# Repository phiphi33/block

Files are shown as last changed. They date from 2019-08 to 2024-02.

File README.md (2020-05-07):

Cette page existe en [Français](https://gitlab.com/tedour/clip-and-block/-/blob/master/README.fr.md).

Clip & block is an open source construction kit (CC By‑SA 4.0). It can create solid structure for electronic projects with a 3D printer. Pieces can be assembly and removed easily for adding and remove components. It is still under development but i present my own projects at the end of this page.
You can follow me on [Mastodon](https://mastodon.social/web/accounts/918095).

# Quickstart in one hour
## Print your first Clip & block
Clip & block is easy to print (no support, it's possible to print it in any direction, not to much précision needed, shapes are simple). 

To start, clone the project locally [GitLab](https://gitlab.com/tedour/clip-and-block/).

First step, you will print first pieces :

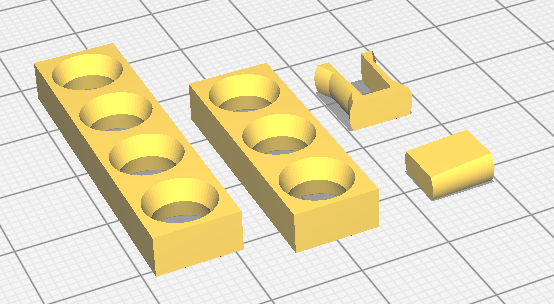
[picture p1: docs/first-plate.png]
first print


### For the pieces :
- go to directory [`stl/basic`](https://gitlab.com/tedour/clip-and-block/-/tree/master/stl/basic) ;
- get the file [`I-3.stl`](https://gitlab.com/tedour/clip-and-block/-/blob/master/stl/basic/I-3.stl) ;
- get the file [`I-4.stl`](https://gitlab.com/tedour/clip-and-block/-/blob/master/stl/basic/I-4.stl).
    
_`I-3.stl` → letter I is for the shape, number 3 is for number of holes._

### Pour le clip et le bloqueur :
- go to directory [`stl/clips`](https://gitlab.com/tedour/clip-and-block/-/tree/master/stl/clips) ;
- get the file [`blocker-2.stl`](https://gitlab.com/tedour/clip-and-block/-/blob/master/stl/clips/blocker-2.stl) (lay it flat, there is a function for that in Cura) ;
- get the file [`clip-2.stl`](https://gitlab.com/tedour/clip-and-block/-/blob/master/stl/clips/clip-2.stl).
    
_number 2 is for the height of the clip (for two pieces deux pièces). `blocker-2.stl` will work only with `clip-2.stl`._

You don't need two much materials for these pieces (2 g and 0,83 m with my settings). 
    
Now, you can assembly pieces ! To unmount, you need to push the blocker from the other side with a small tool. You can print other clips and blockers to play with it and see that it's strong !

# Pieces list
## Existing pieces 
In `stl/basic` directory, there is a big number of pieces (around 75). They are classified by shapes and number of holes (in three dimensions). Here is some samples :
    
| Nom | Image | Description |
| --- | --- | --- |
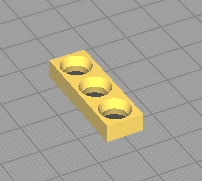
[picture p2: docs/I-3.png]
| I-3 |  | I : in length, 3 holes length |
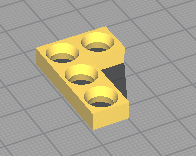
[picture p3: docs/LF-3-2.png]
LF
|  LF-3-2 |  | LF : in L flat, 3 holes length, 2 on the other side |
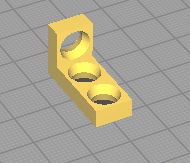
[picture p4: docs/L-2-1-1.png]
| L-2-1-1 |  | L : in L, 2 holes length, 1 height, 1 width |
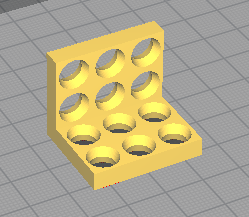
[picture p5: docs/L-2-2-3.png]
| L-2-2-3 |  | L : in L, 2 holes length, 2 height, 3 width |
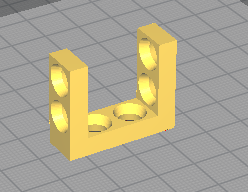
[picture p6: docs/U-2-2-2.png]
| U-2-2-2 |  | U : in  U |
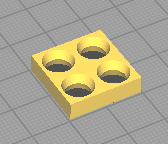
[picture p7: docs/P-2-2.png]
| P-2-2 |    | P : Flat |
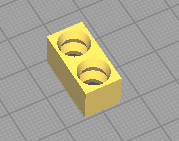
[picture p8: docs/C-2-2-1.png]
| C-2-2-1 |  | C : cube, 2 holes length, 2 height, 1 width |
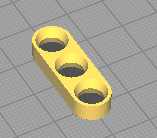
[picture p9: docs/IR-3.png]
| IR-3 |   | IR : in length, rounded (for pieces in rotation) |
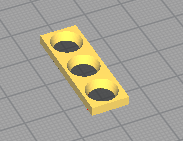
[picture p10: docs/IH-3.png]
| IH-3 |   | IH : in length, half height |
| IHR-3 |  I  | IHR : in length, half height, rounded |

_Perhaps i will remove some shape (C and P can do the same for example)…_

## Create your own pieces
If you can't find the piece you need, you can create your own with [OpenSCAD](https://www.openscad.org/), it's not so hard. For example, i describe here how to create piece P‑2‑3 (flat piece in 2 × 3) :
    
- open file [clip_and_block.scad](https://gitlab.com/tedour/clip-and-block/-/blob/master/clip_and_block.scad)
- modify `model` for the type to **P** ;
- modify `length1` for the length to **2** ;
- modify `length2` for the width to **3** ;
- you can preview with key `F6` ;
- and you can export to STL from OpenSCAD.
    
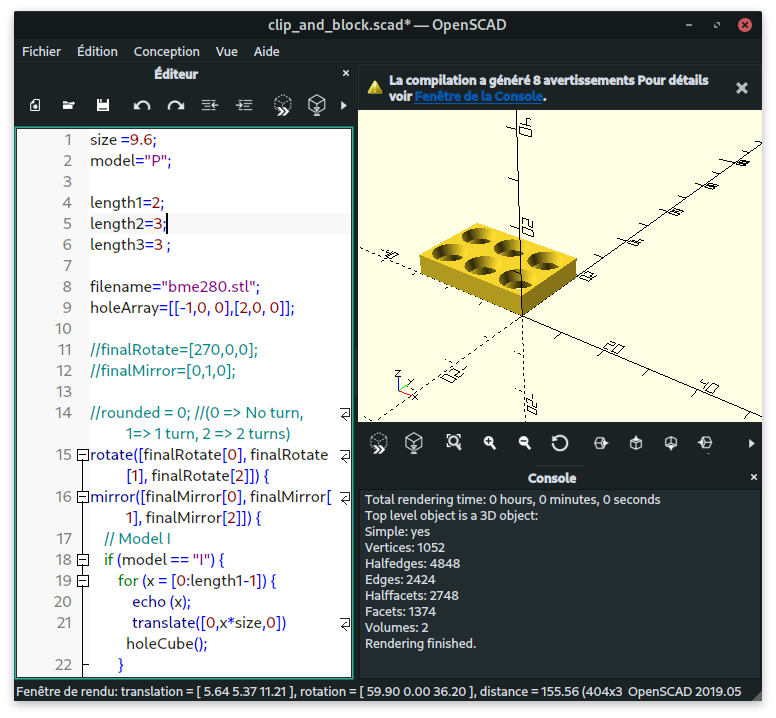
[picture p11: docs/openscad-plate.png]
OpenSCAD


# Pieces for electronic components
It's the interessant part of the project : you can integrate electronic components in clip&block.

## Existing components
I have create pieces for specific components. They are in the directory [`stl/electronic`](https://gitlab.com/tedour/clip-and-block/-/blob/master/stl/electronic).
    
For example, here are the two pieces that can include [NodeMCU](https://fr.wikipedia.org/wiki/NodeMCU) (I love this card :) ) :
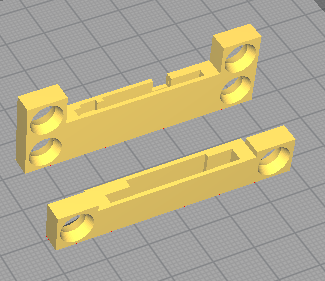
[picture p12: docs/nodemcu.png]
NodeMCU

    
There is a lot of types of this pieces, with more or less holes, only on one side, etc. Here is the list of components that you can find in Clip & block. This list is growing and is not up to date :
    
|  Nom | Image | Description |
| ---: | :----: | :---|
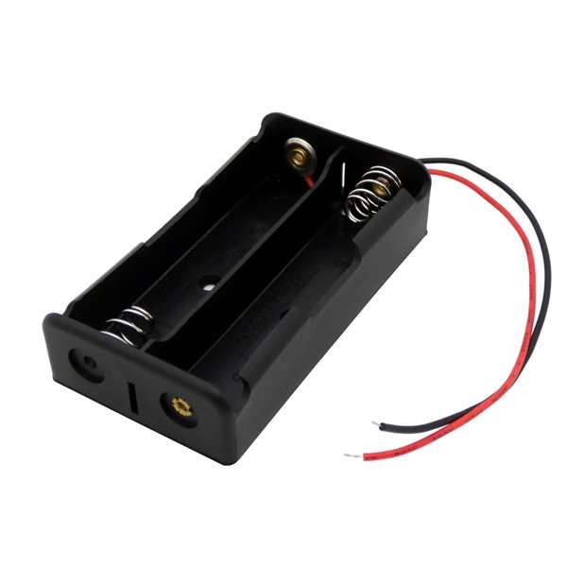
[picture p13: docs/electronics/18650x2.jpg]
|18650x2 Batterie holder |  | Power supply 7,4 V |
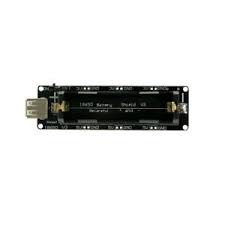
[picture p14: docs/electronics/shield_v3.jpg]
|18650 Batterie shield V3 |  |  Power supply USB + 3,3 V + 5 V + recharge |
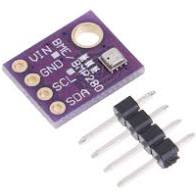
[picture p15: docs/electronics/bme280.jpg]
BME280
| BME 280 |  | Temperature |
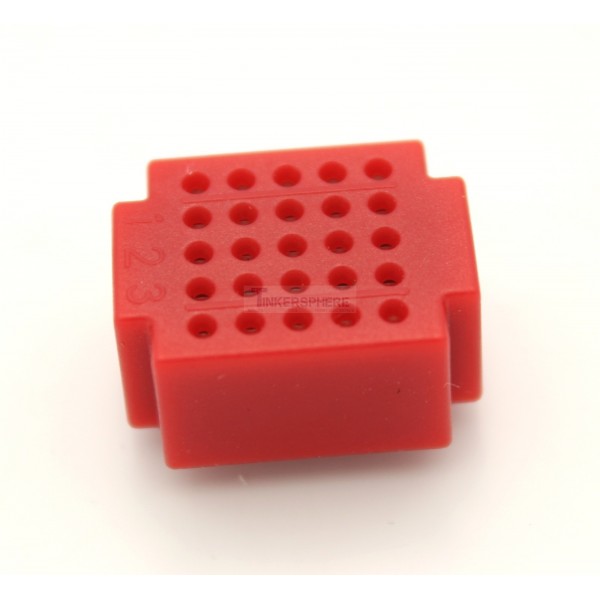
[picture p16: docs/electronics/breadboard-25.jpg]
breadboard25
| Breadboard 25 holes |  | Breadboard |
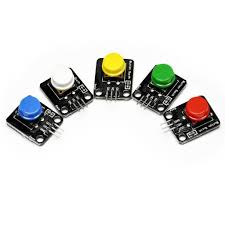
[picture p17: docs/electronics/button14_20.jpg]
button
| Button 14 × 20 |  | Button |
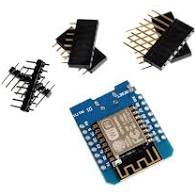
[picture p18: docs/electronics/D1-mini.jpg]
D1-mini
| D1 Mini |  | Developpement card |
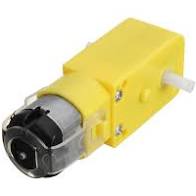
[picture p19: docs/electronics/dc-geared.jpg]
DC-motor
| DC Motor with gearbox |  | DC Motor |
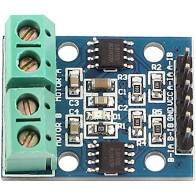
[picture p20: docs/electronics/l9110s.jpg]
l9110S
| L9110s Driver motor |  | DC motor driver
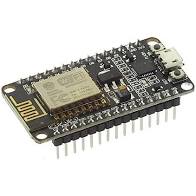
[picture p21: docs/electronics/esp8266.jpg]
nodemcu
| NodeMCU |  | Developpement card |
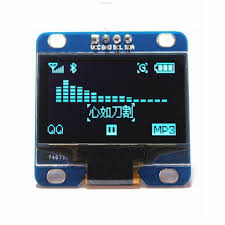
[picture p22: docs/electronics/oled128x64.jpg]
Afficheur OLED
| OLED 128 × 64 |  | OLED screen |
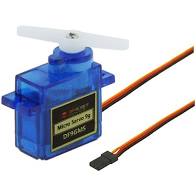
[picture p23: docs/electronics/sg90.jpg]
oled
| SG90 (une seule variante, à améliorer) |  | Servo motor |
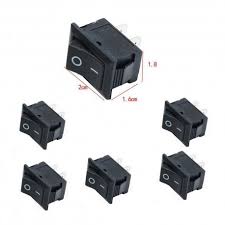
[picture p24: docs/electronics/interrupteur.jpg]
| Simple switch |  | Switch
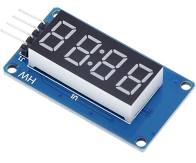
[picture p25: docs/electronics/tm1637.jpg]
| Display TM1637 |  | Display 4 × 7 segments |
    
I let you explore screenshots in the directory [`stl/electronic`].

## Create pieces for your own components
To create pieces for your own components you need to use your favorite CAD software to create the piece without holes. Your piece must be a multiple of 9,6mm length and with and a multiple of 4.8mm for the height.
    
After, you can had holes around your piece with OpenSCAD.

### Create the STL file of your component
Here is how i've worked with the TM1637 4-digit 7-segment :
    
- i've create a piece for the top and one for the bottom to "trap" the TM1637;
- next, i've create edges around to get a multiple of 9,6 mm (here, 48 mm : 5 holes × 28,8 mm et 3 holes × 4,8 mm heigth).
    
Top :
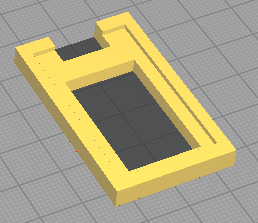
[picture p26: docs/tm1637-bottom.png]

    
Bottom :
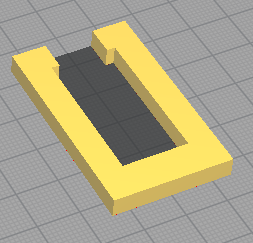
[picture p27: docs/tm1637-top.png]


### Adding holes with OpenScad
    
- open file [`clip_and_block.scad`](https://gitlab.com/tedour/clip-and-block/-/blob/master/clip_and_block.scad) ;
- put your STL file in the directory [`import`](https://gitlab.com/tedour/clip-and-block/-/blob/master/import) ;
- modify the parameter `model` for the type of piece at **F** (_Filename_) — for half height, choose **FH** ;
- in the array **holeArray**, enter coordinates of the holes (test to find the good ones) ;
- in the array **finalRotate**, you can turn your final piece;
- in the array **finalMirror**, you can mirror your final piece.
    
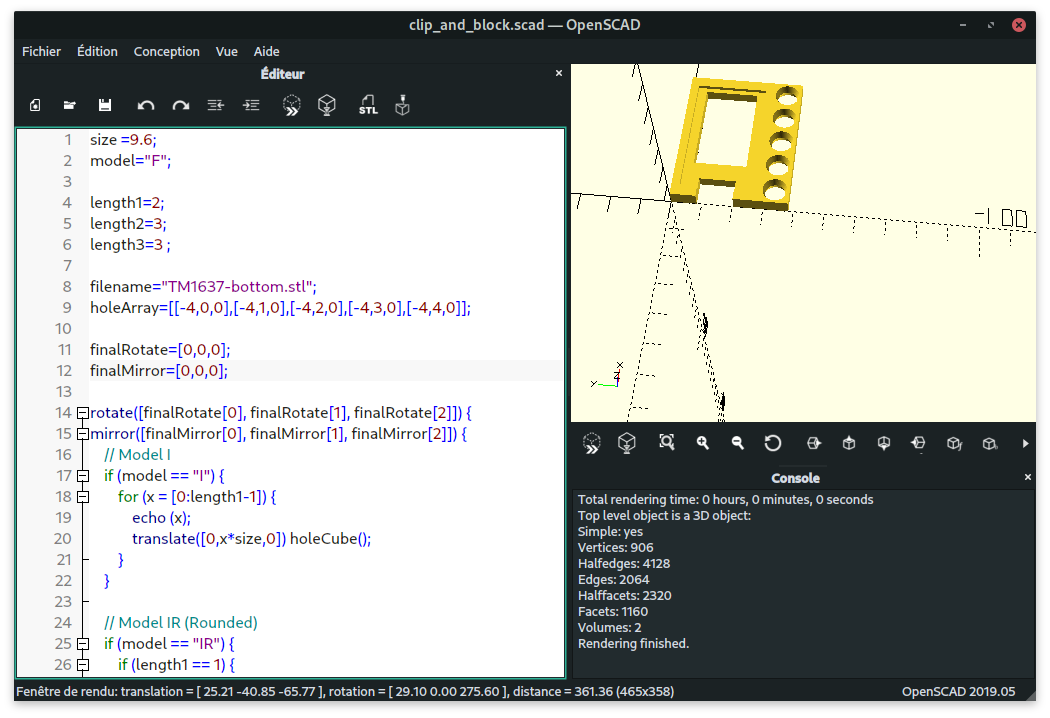
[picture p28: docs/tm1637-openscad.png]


# My projects with Clip&Block
Here are the projects i've create with Clip & blocks — feel free to ask me if you want more details about them :
    
- [Virtual Wall Roomba](https://www.thingiverse.com/thing:3413412) (mur virtuel pour aspirateur automatique) :
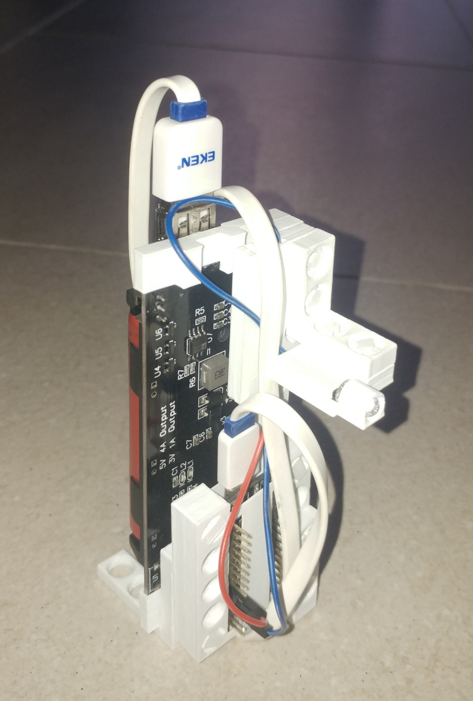
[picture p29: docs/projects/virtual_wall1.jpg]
Virtual Wall

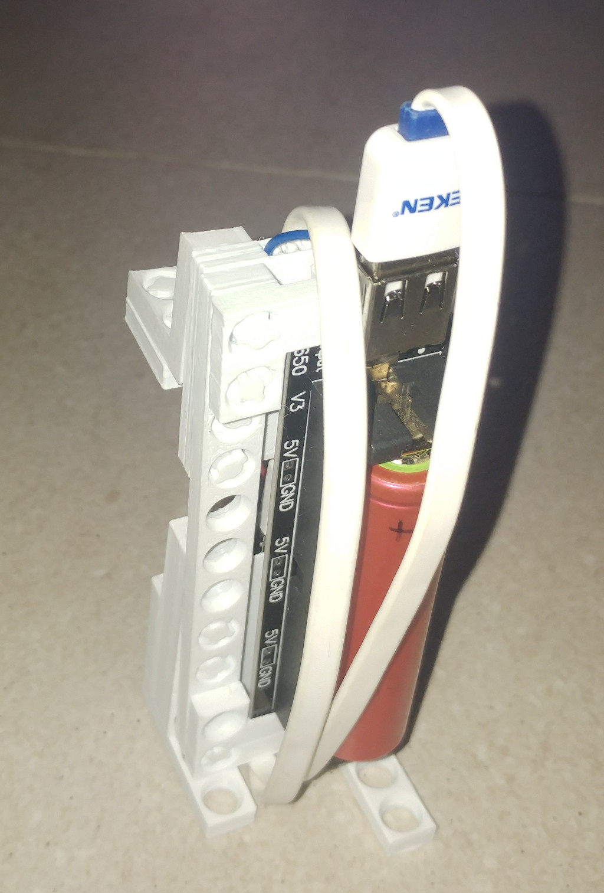
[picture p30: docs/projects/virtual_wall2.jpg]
Virtual Wall

    
- [electronic hourglass](https://www.thingiverse.com/thing:3413412) (To use in the morning with my childrens :)) :
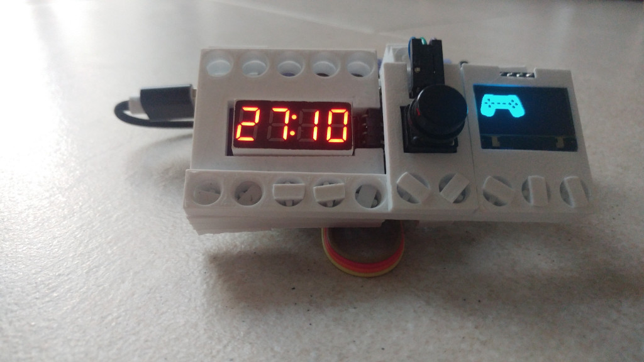
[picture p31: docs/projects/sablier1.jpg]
Sablier

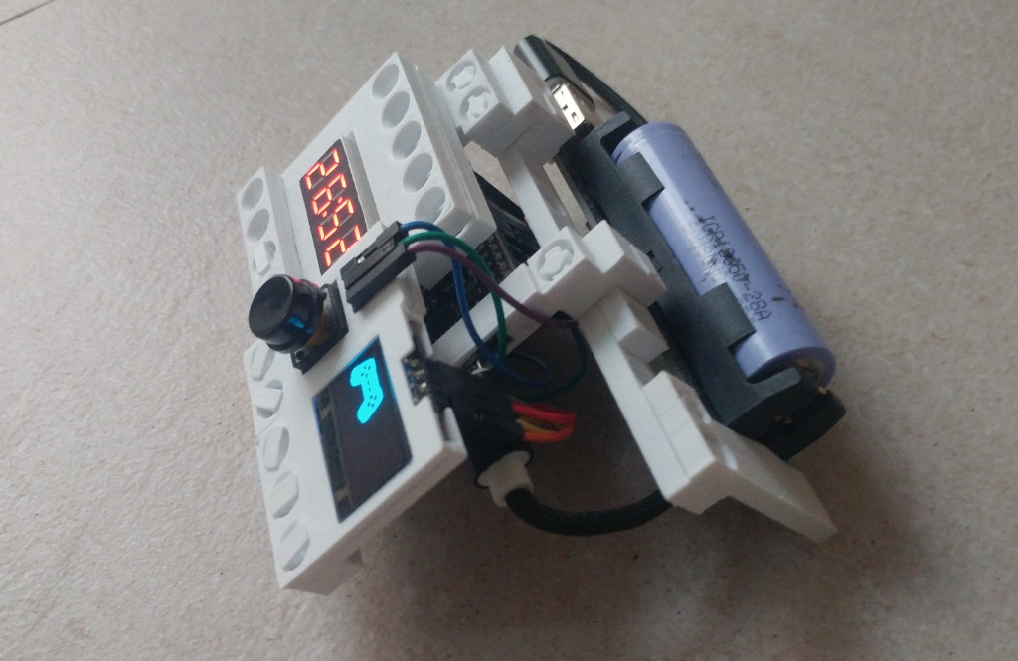
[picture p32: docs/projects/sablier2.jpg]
Sablier

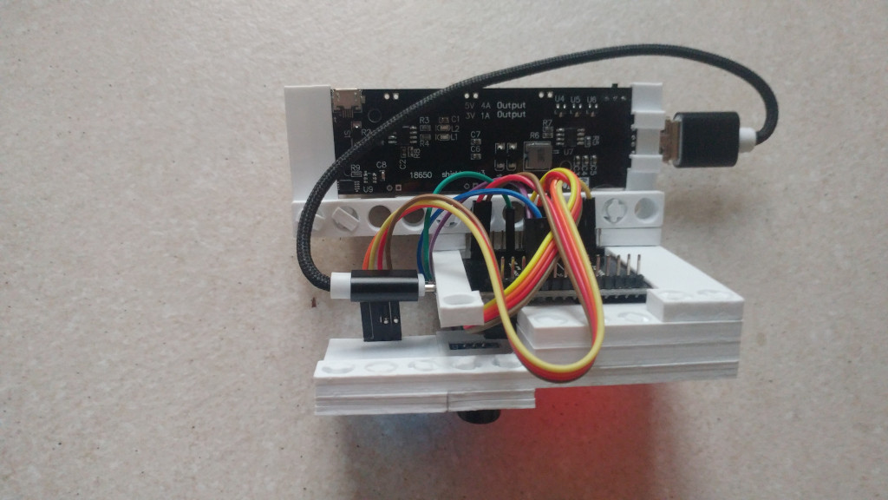
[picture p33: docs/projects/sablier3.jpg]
Sablier

    
- RC-CAR (based on my project [FF RC-Car](https://www.thingiverse.com/thing:3133996)) :
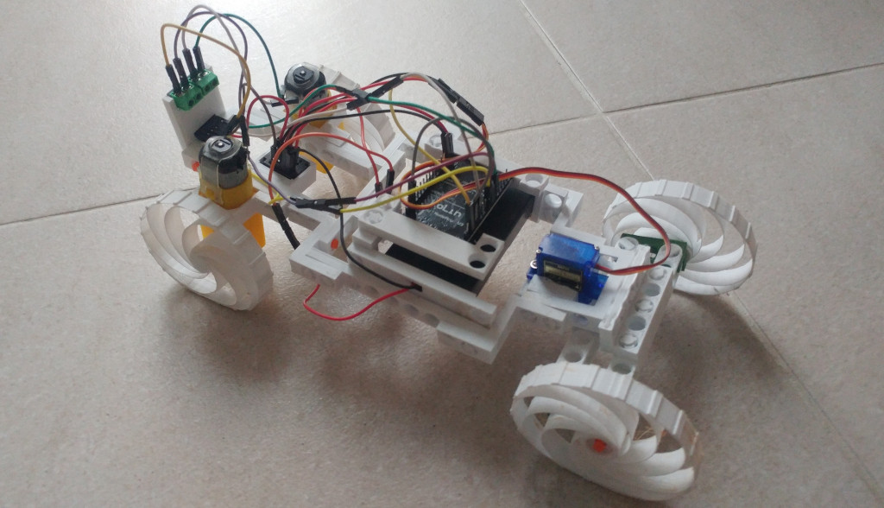
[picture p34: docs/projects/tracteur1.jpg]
Tracteur

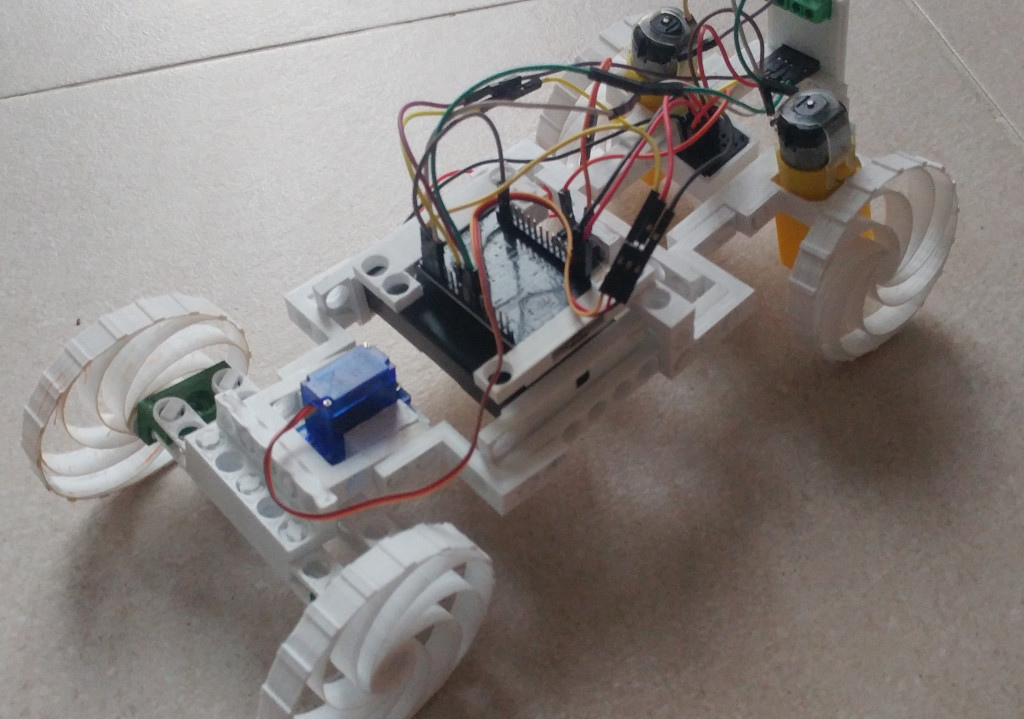
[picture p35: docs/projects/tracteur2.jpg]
Tracteur


## Testing needed
Please test Clip&Block and tell me what you think about it on mastodon with the hashtag #clip_block !

## Create a community around Clip&Block
For now, i only have my Gitlab [GitLab](https://gitlab.com/tedour/clip-and-block). But you can follow my [Mastodon account](https://mastodon.social/web/accounts/918095) to discuss, if we could be two or three it could make things better. :)

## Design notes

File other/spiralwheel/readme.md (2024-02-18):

Must be as it for clip wheels :
IR1 - Wheel - whasher

Using clip-3-M4.stl is a good idea, else, use clip-3 with a strong blocker

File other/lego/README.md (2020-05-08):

# LEGO.scad

An OpenSCAD LEGO-compatible brick generator.

This parametric brick takes the popular work of http://www.thingiverse.com/thing:5699 a couple steps further, adding easy Customizer support and support for generating wings, smooth-topped tiles, DUPLO-style bricks, sloped bricks, Technic-style holes, and more.

Depending on the resolution of your printer, you may not be able to print pieces that fit exactly with standard LEGO blocks. If you do print any of these bricks, I'd be interested to know whether they fits together with other bricks, especially if you have an SLS or SLA printer.

These blocks are not strictly identical to LEGO bricks, but they should be compatible in most every way.

See http://www.chrisfinke.com/2015/01/27/3d-printed-lego-compatible-bricks/ for more details.

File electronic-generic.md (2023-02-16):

# use electronic-generic
The easiest way to use it is to print each corner you need from the directory /stl/electronic-parts/electronic-generic

You have to be sure that the electronic card have enough place on each corner (Corners are 3.6mm)
## Step one : get the size of the component
For example, for the module ESP32-CAM, the size is 39.4mm x 26.8mm

## Define a grid of holes
You need to have a minimum of 1mm on each side of the module. So here is the number of holes for the size :

|# of holes|size|max size for the module|
|---|---|---|
|2 holes|19.2|17.2|
|3 holes|28.8|26.8|
|4 holes|38.4|36.4|
|5 holes|48.0|46.0|
|6 holes|57.6|55.6|
|7 holes|67.2|65.2|
|8 holes|76.8|74.8|
|9 holes|86.4|84.6|
|10 holes|96.0|94.0|

So the number of holes for the module 39.4mm x 26.8mm is 5x3 

## Define the rest of mm
With 5 holes, you have 48mm - 39.4 mm = 8mm (4mm each side)
With 3 holes, you have 28.8mm - 26.8 mm = 2mm (1mm each side)

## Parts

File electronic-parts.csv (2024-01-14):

Directory | Filename | STL_source | Model | holeArray | finalRotate | finalMirror
sg90 | sg90-helix-2.stl | sg90-helix.stl | F | [-1,0,0],[-1,1,0] | [0,270,0] | []
sg90 | sg90-helix-4.stl | sg90-helix.stl | F | [-1,0,0],[-1,1,0],[1,0,0],[1,1,0] | [0,270,0] | []
sg90 | sg90-helix-1.stl | sg90-helix.stl | F | [0,-1,0] | [0,270,0] | []
breadboard | breadboard25-2.stl | breadboard25.stl | F | [0,-1,0],[1,-1,0] | [] | []
breadboard | breadboard25-3.stl | breadboard25.stl | F | [-1,0,0],[-1,1,0],[-1,2,0] | [] | []
oled-128x64 | oled-128x64-top-2side.stl | oled-128x64-top.stl | FH | [-1,0,0],[-1,1,0],[-1,2,0],[3,0,0],[3,1,0],[3,2,0] | [0,0,0] | [0,0,0]
oled-128x64 | oled-128x64-top-1side.stl | oled-128x64-top.stl | FH | [-1,0,0],[-1,1,0],[-1,2,0] | [0,0,0] | [0,0,0]
oled-128x64 | oled-128x64-bottom-2side.stl | oled-128x64-bottom.stl | FH | [-1,0,0],[-1,1,0],[-1,2,0],[3,0,0],[3,1,0],[3,2,0] | [0,0,0] | [0,0,0]
oled-128x64 | oled-128x64-bottom-1side.stl | oled-128x64-bottom.stl | FH | [-1,0,0],[-1,1,0],[-1,2,0] | [0,0,0] | [0,0,0]
oled-128x64 | oled-128x64-big-2side.stl | oled-128x64-big.stl | FH | [-1,0,0],[-1,1,0],[-1,2,0],[3,0,0],[3,1,0],[3,2,0] | [0,0,0] | [0,0,0]
oled-128x64 | oled-128x64-big-1side.stl | oled-128x64-big.stl | FH | [-1,0,0],[-1,1,0],[-1,2,0] | [0,0,0] | [0,0,0]
battery-shield | battery-shield-bottom-1.stl | battery-shield-bottom.stl | F | [-1,0,0] | [90,0,0] | [0,1,0]
battery-shield | battery-shield-bottom-2.stl | battery-shield-bottom.stl | F | [-1,0,0],[-2,0,0] | [90,0,0] | [0,1,0]
battery-shield | battery-shield-usb-1.stl | battery-shield-usb.stl | F | [0,0,0] | [90,0,0] | [1,0,0]
battery-shield | battery-shield-usb-2.stl | battery-shield-usb.stl | F | [0,0,0],[1,0,0] | [90,0,0] | [1,0,0]
esp32-30 | esp32-30.stl | esp32-30.stl | F |  | [0,0,0] | [0,0,0]
joystick | joystick-generic.stl | joystick-generic.stl | F |  | [0,0,0] | [0,0,0]
nodemcu | nodemcu-generic.stl | nodemcu-generic.stl | F |  | [0,0,0] | [0,0,0]
esp32-cam | esp32-cam.stl | esp32-cam.stl | F |  | [0,0,0] | [0,0,0]
rc522 | rc522.stl | rc522.stl | F |  | [0,0,0] | [0,0,0]
tm1638 | tm1638.stl | tm1638.stl | F |  | [0,0,0] | [0,0,0]
pn532 | pn532.stl | pn532.stl | F |  | [0,0,0] | [0,0,0]
D1-mini | D1-mini-generic.stl | D1-mini-generic.stl | F |  | [0,0,0] | [0,0,0]
generic-corner | generic-corner-1-12.stl | generic-corner12.stl | F | [-1,0,0] | [0,270,0] | [0,0,0]
generic-corner | generic-corner-1-24.stl | generic-corner24.stl | F | [-1,0,0] | [0,270,0] | [0,0,0]
generic-corner | generic-corner-1-36.stl | generic-corner36.stl | F | [-1,0,0] | [0,270,0] | [0,0,0]
generic-corner | generic-corner-1-48.stl | generic-corner48.stl | F | [-1,0,0] | [0,270,0] | [0,0,0]
generic-corner | generic-corner-1-60.stl | generic-corner60.stl | F | [-1,0,0] | [0,270,0] | [0,0,0]
tm1637 | tm1637-bottom.stl | TM1637-bottom.stl | F | [0,0,0],[0,1,0],[0,2,0],[0,3,0],[0,4,0],[-4,0,0],[-4,1,0],[-4,2,0],[-4,3,0],[-4,4,0] | [0,0,0] | [0,0,0]
tm1637 | tm1637-top.stl | TM1637-top.stl | F | [0,0,0],[0,1,0],[0,2,0],[0,3,0],[0,4,0],[-4,0,0],[-4,1,0],[-4,2,0],[-4,3,0],[-4,4,0] | [0,0,0] | [0,0,0]
tm1637 | tm1637-1other-side-bottom.stl | TM1637-bottom.stl | F | [-4,0,0],[-4,1,0],[-4,2,0],[-4,3,0],[-4,4,0] | [0,0,0] | [0,0,0]
tm1637 | tm1637-1other-side-top.stl | TM1637-top.stl | F | [0,0,0],[0,1,0],[0,2,0],[0,3,0],[0,4,0] | [0,0,0] | [0,0,0]
tm1637 | tm1637-1side-bottom.stl | TM1637-bottom.stl | F | [0,0,0],[0,1,0],[0,2,0],[0,3,0],[0,4,0] | [0,0,0] | [0,0,0]
tm1637 | tm1637-1side-top.stl | TM1637-top.stl | F | [-4,0,0],[-4,1,0],[-4,2,0],[-4,3,0],[-4,4,0] | [0,0,0] | [0,0,0]
tm1637 | tm1637-small-bottom.stl | TM1637-bottom.stl | F | [-1,5,0],[-2,5,0],[-3,5,0] | [0,0,0] | [0,0,0]
tm1637 | tm1637-small-top.stl | TM1637-top.stl | F | [-1,5,0],[-2,5,0],[-3,5,0] | [0,0,0] | [0,0,0]
arduino-nano | nano-bottom-2side.stl | nano-bottom.stl | F | [-1,0,0],[-1,1,0],[-1,2,0],[-1,3,0],[-1,4,0],[2,0,0],[2,1,0],[2,2,0],[2,3,0],[2,4,0] | [0,270,0] | [0,0,0]
arduino-nano | nano-top-2side.stl | nano-top.stl | F | [-1,0,0],[-1,1,0],[-1,2,0],[-1,3,0],[-1,4,0],[2,0,0],[2,1,0],[2,2,0],[2,3,0],[2,4,0] | [0,270,0] | [0,0,0]
n20-geared | n20-geared-double.stl | n20-geared-double.stl | F | [-1,-1,0],[-1,1,0],[-2,-1,0],[-2,1,0] | [0,0,0] | [0,0,0]
n20-geared | n20-geared.stl | n20-geared.stl | F | [-1,-1,0],[-1,1,0] | [0,0,0] | [0,0,0]
wire | wire-1H.stl | wire-1H.stl | FH | [0,-1,0],[0,1,0] | [0,0,0] | [0,0,0]
wire | wire-2H.stl | wire-2H.stl | FH | [0,-1,0],[0,2,0] | [0,0,0] | [0,0,0]
wire | wire-3H.stl | wire-3H.stl | FH | [0,-1,0],[0,3,0] | [0,0,0] | [0,0,0]
wire | wire-3H-strong.stl | wire-3H-strong.stl | F | [0,-1,0],[0,3,0] | [0,0,0] | [0,0,0]
wire | wire-4H.stl | wire-4H.stl | FH | [0,-1,0],[0,4,0] | [0,0,0] | [0,0,0]
wire | wire-4H-strong.stl | wire-4H-strong.stl | F | [0,-1,0],[0,4,0] | [0,0,0] | [0,0,0]
wire | wire-5H.stl | wire-5H.stl | FH | [0,-1,0],[0,5,0] | [0,0,0] | [0,0,0]
wire | wire-5H-strong.stl | wire-5H-strong.stl | F | [0,-1,0],[0,5,0] | [0,0,0] | [0,0,0]
dupont | dupontx2.stl | dupontx2.stl | FH | [-1,0,0],[-1,1,0],[-1,2,0] | [0,0,0] | [0,0,0]
dupont | dupontx4.stl | dupontx4.stl | FH | [-1,0,0],[-1,1,0],[-1,2,0] | [0,0,0] | [0,0,0]
dupont | dupontx6.stl | dupontx6.stl | FH | [-1,0,0],[-1,1,0],[-1,2,0] | [0,0,0] | [0,0,0]
wire | wire-3.stl | wire-3.stl | F | [0,-1,0] | [0,0,0] | [0,0,0]
wire | wire-3-otherside.stl | wire-3.stl | F | [0,-1,0] | [0,0,0] | [1,0,0]
wire | wire-3-2side.stl | wire-3.stl | F | [0,-1,0],[0,1,0] | [0,0,0] | [0,0,0]
wire | wire-6.stl | wire-6.stl | F | [0,-1,0] | [0,0,0] | [0,0,0]
wire | wire-6-otherside.stl | wire-6.stl | F | [0,-1,0] | [0,0,0] | [1,0,0]
wire | wire-6-2side.stl | wire-6.stl | F | [0,-1,0],[0,2,0] | [0,0,0] | [0,0,0]
sg90 | sg90-2x1.stl | sg90-2x1.stl | F | [0,-1,0],[1,-1,0],[0,2,0],[1,2,0] | [0,0,0] | [0,0,0]
sg90 | sg90-2x1-front.stl | sg90-2x1.stl | F | [-1,0,0],[-1,1,0] | [0,0,0] | [0,0,0]
sg90 | sg90-2x1-1side.stl | sg90-2x1.stl | F | [0,-1,0],[1,-1,0] | [0,0,0] | [0,0,0]
sg90 | sg90-3x1.stl | sg90-3x1.stl | F | [0,-1,0],[1,-1,0],[2,-1,0],[0,2,0],[1,2,0],[2,2,0] | [0,0,0] | [0,0,0]
sg90 | sg90-3x1-1side.stl | sg90-3x1.stl | F | [0,-1,0],[1,-1,0],[2,-1,0] | [0,0,0] | [0,0,0]
sg90 | sg90-2x2.stl | sg90-2x2.stl | F | [0,-1,0],[1,-1,0],[0,-1,1],[1,-1,1],[0,2,0],[1,2,0],[0,2,1],[1,2,1] | [0,0,0] | [0,0,0]
sg90 | sg90-4x1.stl | sg90-4x1.stl | F | [0,-1,0],[1,-1,0],[2,-1,0],[3,-1,0],[0,2,0],[1,2,0],[2,2,0],[3,2,0] | [0,0,0] | [0,0,0]
sg90 | sg90-4x1-large.stl | sg90-4x1-large.stl | F | [0,-1,0],[1,-1,0],[2,-1,0],[3,-1,0],[0,3,0],[1,3,0],[2,3,0],[3,3,0] | [0,0,0] | [0,0,0]
sg90 | sg90-4x1-front.stl | sg90-4x1.stl | F | [-1,0,0],[-1,1,0],[4,0,0],[4,1,0] | [0,0,0] | [0,0,0]
sg90 | sg90-4x1-1side.stl | sg90-4x1.stl | F | [0,-1,0],[1,-1,0],[2,-1,0],[3,-1,0] | [0,0,0] | [0,0,0]
bme280 | bme280.stl | bme280.stl | FH | [-1,0,0],[2,0,0] | [0,0,0] | [0,0,0]
l9110s | l9110s-side.stl | l9110s.stl | FH | [0,-1,0],[1,-1,0],[2,-1,0],[0,3,0],[1,3,0],[2,3,0] | [0,0,0] | [0,0,0]
l9110s | l9110s-bottom.stl | l9110s.stl | FH | [-1,0,0],[-1,1,0],[-1,2,0] | [0,0,0] | [0,0,0]
nodemcu | nodemcu-bottom.stl | nodemcu-bottom.stl | F | [-5,0,0] | [0,270,0] | [0,0,0]
nodemcu | nodemcu-bottom-2.stl | nodemcu-bottom.stl | F | [-5,0,0],[-5,1,0] | [0,270,0] | [0,0,0]
nodemcu | nodemcu-bottom-2side.stl | nodemcu-bottom.stl | F | [0,0,0],[-5,0,0] | [0,270,0] | [0,0,0]
nodemcu | nodemcu-top-small.stl | nodemcu-top-small.stl | F | [0,-1,0],[0,4,0] | [90,0,0] | [0,0,0]
nodemcu | nodemcu-top-small-1side.stl | nodemcu-top-small.stl | F | [0,-1,0] | [90,0,0] | [0,0,0]
nodemcu | nodemcu-top-2side.stl | nodemcu-top.stl | F | [0,-1,0],[0,4,0] | [90,0,0] | [0,0,0]
nodemcu | nodemcu-top-2side2.stl | nodemcu-top.stl | F | [0,-1,0],[0,4,0],[1,-1,0],[1,4,0] | [90,0,0] | [0,0,0]
nodemcu | nodemcu-top-1side2.stl | nodemcu-top.stl | F | [0,-1,0],[1,-1,0] | [90,0,0] | [0,0,0]
18650x2 | 18650x2-holder-bottom.stl | 18650x2-holder.stl | F | [-1,0,0],[-1,1,0],[-1,2,0],[-1,3,0],[-1,4,0] | [0,0,0] | [0,0,0]
18650x2 | 18650x2-holder-1.stl | 18650x2-holder.stl | F | [0,-1,0],[0,5,0] | [0,0,0] | [0,0,0]
18650x2 | 18650x2-holder.stl | 18650x2-holder.stl | F | [0,-1,0],[1,-1,0],[0,5,0],[1,5,0] | [0,0,0] | [0,0,0]
button14x20 | button14x20-bottom-1side.stl | button14x20-half-bottom.stl | FH | [-1,0,0],[-1,1,0],[-1,2,0] | [0,0,0] | [0,0,0]
button14x20 | button14x20-top-1side.stl | button14x20-half-top.stl | FH | [2,0,0],[2,1,0],[2,2,0] | [0,0,0] | [0,0,0]
button14x20 | button14x20-bottom-2side.stl | button14x20-half-bottom.stl | FH | [-1,0,0],[-1,1,0],[-1,2,0],[2,0,0],[2,1,0],[2,2,0] | [0,0,0] | [0,0,0]
button14x20 | button14x20-top-2side.stl | button14x20-half-top.stl | FH | [-1,0,0],[-1,1,0],[-1,2,0],[2,0,0],[2,1,0],[2,2,0] | [0,0,0] | [0,0,0]
button14x20 | button14x20-bottom-small.stl | button14x20-half-bottom.stl | FH | [0,3,0],[1,3,0] | [0,0,0] | [0,0,0]
button14x20 | button14x20-top-small.stl | button14x20-half-top.stl | FH | [0,3,0],[1,3,0] | [0,0,0] | [0,0,0]
button14x20 | button14x20-half-topx2-2side.stl | button14x20-half-topx2.stl | FH | [-1,0,0],[-1,1,0],[-1,2,0],[4,0,0],[4,1,0],[4,2,0] | [0,0,0] | [0,0,0]
button14x20 | button14x20-half-topx2-1side.stl | button14x20-half-topx2.stl | FH | [0,3,0],[1,3,0],[2,3,0],[3,3,0] | [0,0,0] | [0,0,0]
button14x20 | button14x20-half-bottomx2-2side.stl | button14x20-half-bottomx2.stl | FH | [-1,0,0],[-1,1,0],[-1,2,0],[4,0,0],[4,1,0],[4,2,0] | [0,0,0] | [0,0,0]
button14x20 | button14x20-half-bottomx2-1side.stl | button14x20-half-bottomx2.stl | FH | [0,3,0],[1,3,0],[2,3,0],[3,3,0] | [0,0,0] | [0,0,0]
dc-motor-gear | dc-motor-v2.stl | dc-motor-v2.stl | F | [-1,-1,0],[-1,3,0] | [90,0,0] | [1,0,0]
dc-motor-gear | dc-motor-v2-double.stl | dc-motor-v2.stl | F | [-1,-1,0],[-1,3,0],[-1,4,0] | [90,0,0] | [1,0,0]
dc-motor-gear | dc-motor-v2-down.stl | dc-motor-v2-down.stl | F | [-1,-1,0],[-1,3,0] | [270,0,0] | [1,0,0]
dc-motor-gear | dc-motor-v2-down-double.stl | dc-motor-v2-down.stl | F | [-1,-1,0],[-1,3,0],[-1,4,0] | [270,0,0] | [1,0,0]
D1-mini | D1-mini.stl | D1-mini.stl | F | [0,0,0],[0,1,0],[0,2,0],[0,3,0],[-4,0,0],[-4,1,0],[-4,2,0],[-4,3,0] | [0,0,0] | [0,0,0]
D1-mini | D1-mini-one-side.stl | D1-mini.stl | F | [0,0,0],[0,1,0],[0,2,0],[0,3,0] | [0,0,0] | [0,0,0]
D1-mini | D1-mini-other-side.stl | D1-mini.stl | F | [-4,0,0],[-4,1,0],[-4,2,0],[-4,3,0] | [0,0,0] | [0,0,0]
D1-mini | D1-mini-small.stl | D1-mini.stl | F | [-1,-1,0],[-2,-1,0],[-3,-1,0] | [0,0,0] | [0,0,0]

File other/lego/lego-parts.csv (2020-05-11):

Filename | Model | width | length | height | width2 | length2 | holeArray
L1.stl | LE | 1 | 6 | 1/3 | 0 | 0 | [[-1,0,0],[-1,1,0],[-1,2,0],[-1,3,0],[-1,4,0]]
L2.stl | LE | 2 | 6 | 1/3 | 0 | 0 | [[-1,0,0],[-1,1,0],[-1,2,0],[-1,3,0],[-1,4,0]]
L3.stl | LE | 1 | 3 | 1/3 | 0 | 0 | [[-1,0,0],[-1,1,0]]
L4.stl | LE | 2 | 3 | 1/3 | 0 | 0 | [[-1,0,0],[-1,1,0]]
L5.stl | LE | 1 | 3 | 1/3 | 1 | 3 | [[-1,0,0],[-1,1,0]]
L6.stl | LE | 1 | 3 | 1/3 | 1 | 4 | [[-1,0,0],[-1,1,0],[-2,0,0]]
L7.stl | LE | 1 | 2 | 1/3 | 1 | 3 | [[-1,0,0],[-1,1,0],[-2,0,0]]

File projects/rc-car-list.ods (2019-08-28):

 | length | qty | total
Direction |  |  | 7,86
IHR-9 | 0,47 | 4 | 1,88
L-1-1-3 | 0,91 | 2 | 1,82
I-5 | 0,53 | 1 | 0,53
L-1-1-5 | 1,51 | 1 | 1,51
center-SG90 | 0,33 | 1 | 0,33
sg90 | 1,79 | 1 | 1,79
clips |  | 16 | 0
Wheels |  |  | 8,1
spiralwheel-front-65 | 1,95 | 2 | 3,9
spiralwheel-front-washer | 0,11 | 2 | 0,22
IR-1 | 0,07 | 2 | 0,14
spiralwheel-rear-65 | 1,92 | 2 | 3,84
Electronic |  |  | 12,31
nodemcu-bottom-2side | 0,66 | 1 | 0,66
nodemcu-top-2side2 | 1,47 | 1 | 1,47
18650x2-holder | 1,32 | 1 | 1,32
18650x2-holder-1 | 1,11 | 1 | 1,11
l9110s | 0,58 | 2 | 1,16
DC motor | 2,63 | 2 | 5,26
Switch | 0,28 | 1 | 0,28
breadboard25-simple | 1,05 | 1 | 1,05

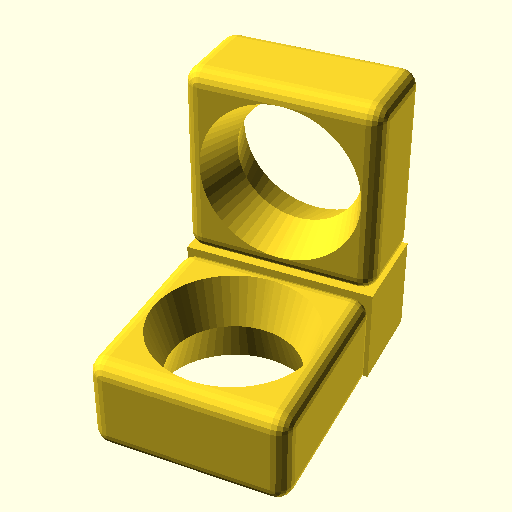
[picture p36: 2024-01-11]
stl/basic-parts/L-1-1-1.png

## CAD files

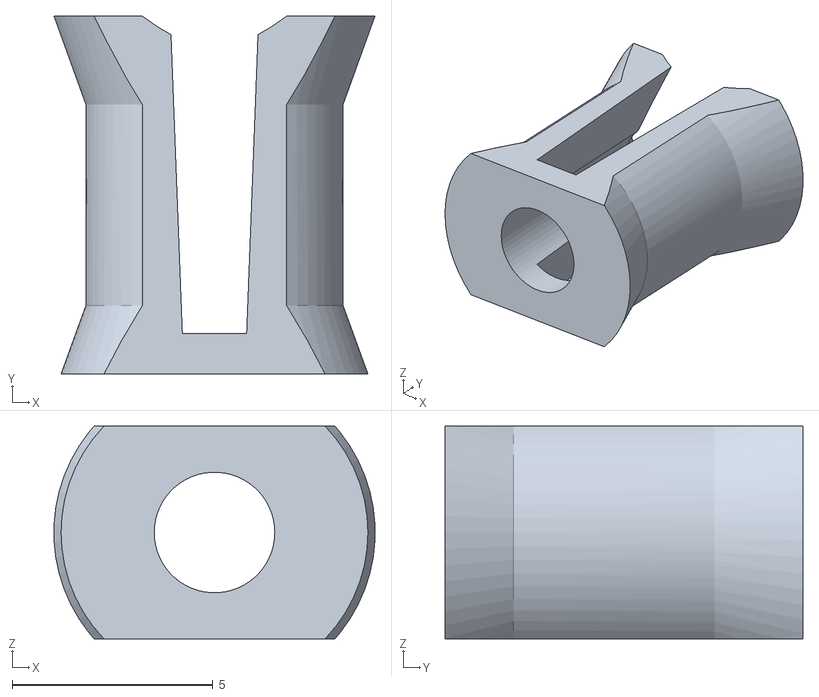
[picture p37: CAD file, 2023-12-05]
imports/Main V3 - clip-2-M4.stl
7.99 x 8.90 x 5.30

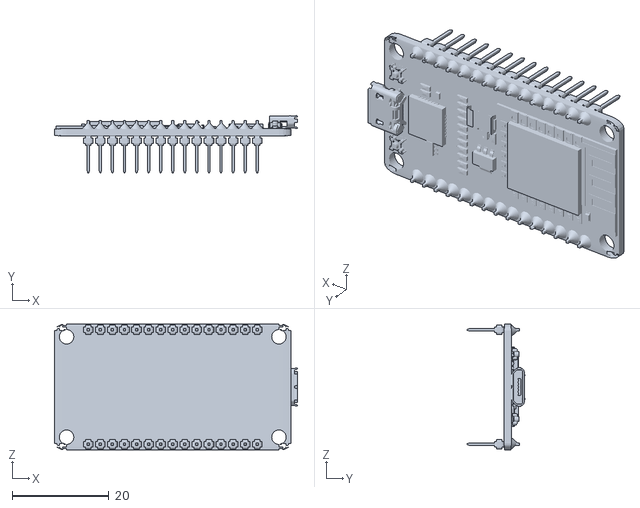
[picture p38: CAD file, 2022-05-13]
dat/bin/binary.stl
50.3 x 11.9 x 26.0

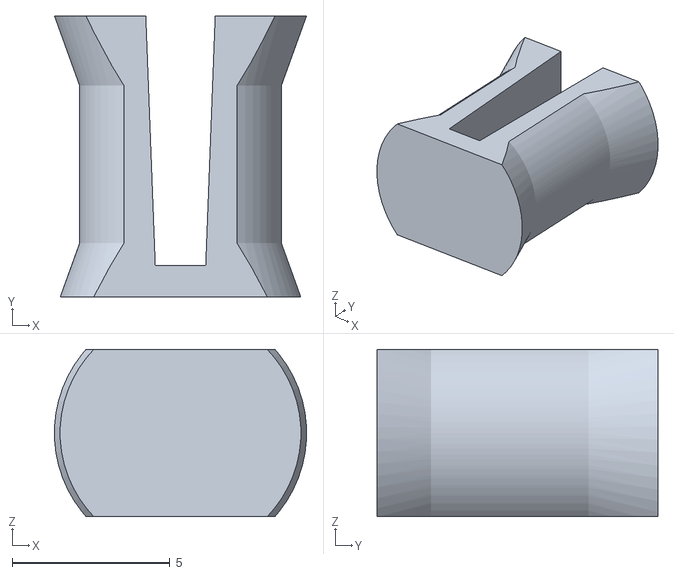
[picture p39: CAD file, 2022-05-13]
dat/clips/clip-2a.stl
7.99 x 8.90 x 5.30

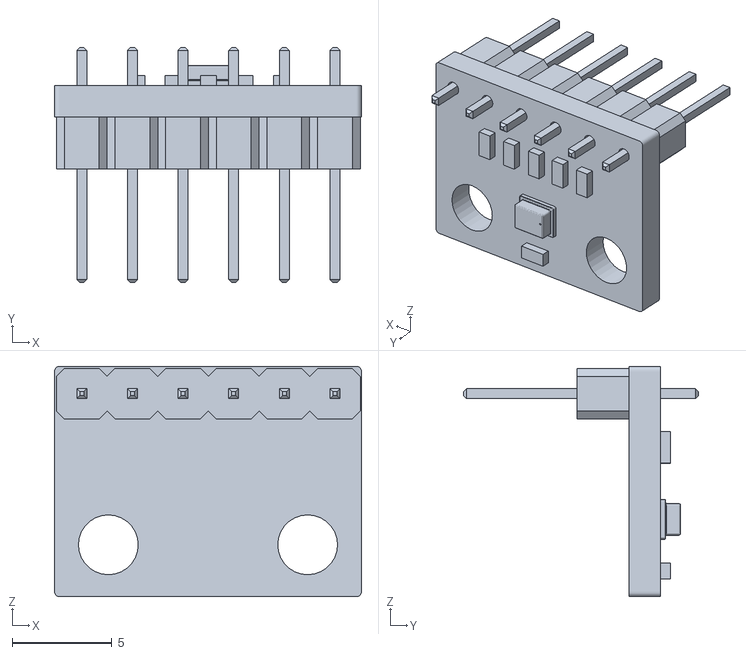
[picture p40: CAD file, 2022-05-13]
dat/other/other-BME280.stl
15.4 x 11.8 x 11.6

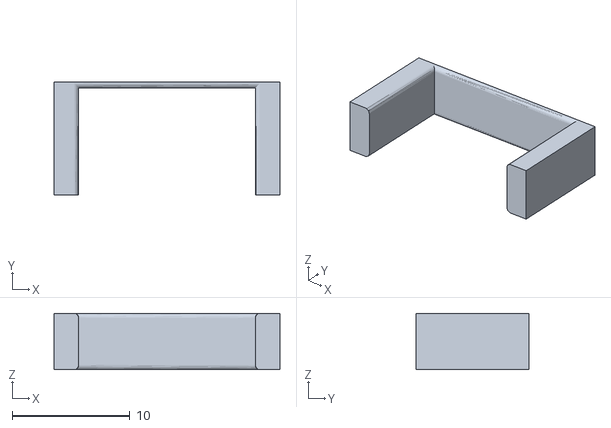
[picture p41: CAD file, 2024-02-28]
imports/switch.stl
19.2 x 9.60 x 4.80

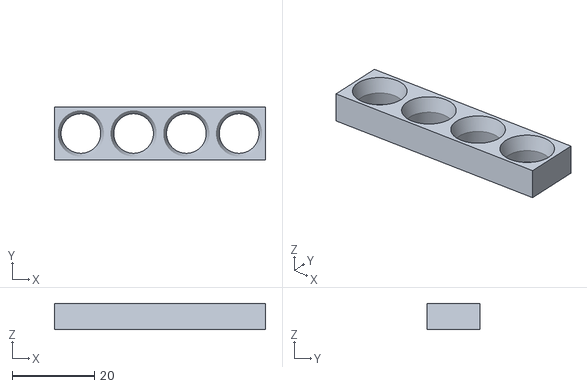
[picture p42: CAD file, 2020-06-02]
other/12.8/stl/basic-parts/C-4-1-1.stl
51.2 x 12.8 x 6.40

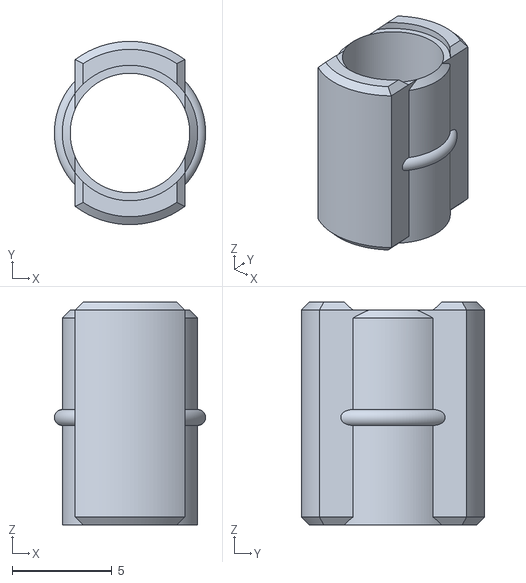
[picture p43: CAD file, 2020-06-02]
other/12.8/stl/clips/blocker-2-line.stl
7.60 x 9.20 x 11.2

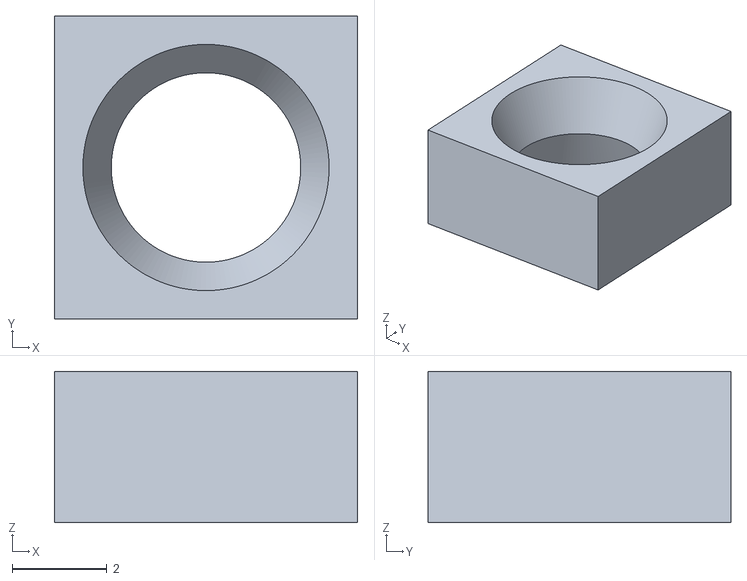
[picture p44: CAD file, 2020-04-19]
other/6.4/imports/hole-cube.stl
6.40 x 6.40 x 3.20

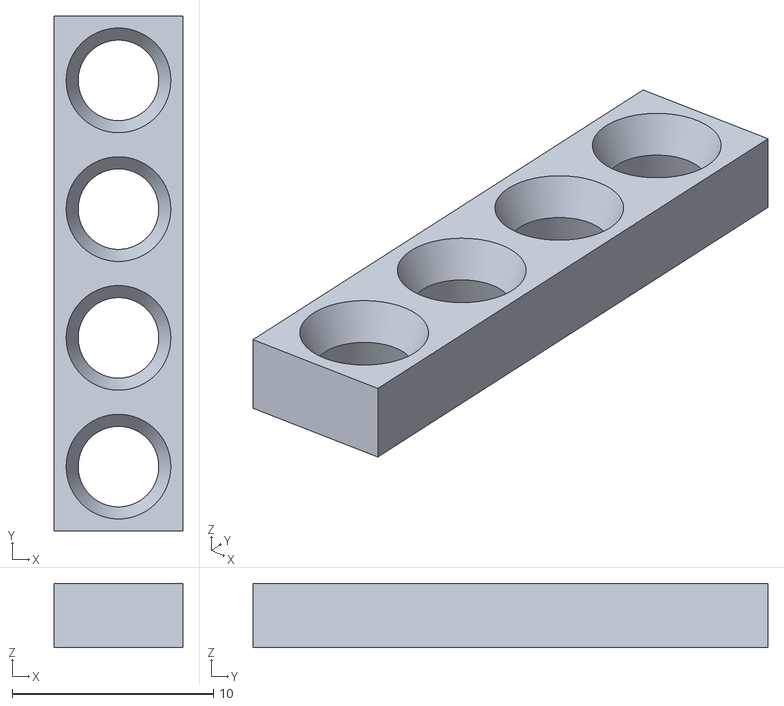
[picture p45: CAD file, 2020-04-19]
other/6.4/stl/basic/I-4.stl
6.40 x 25.6 x 3.20

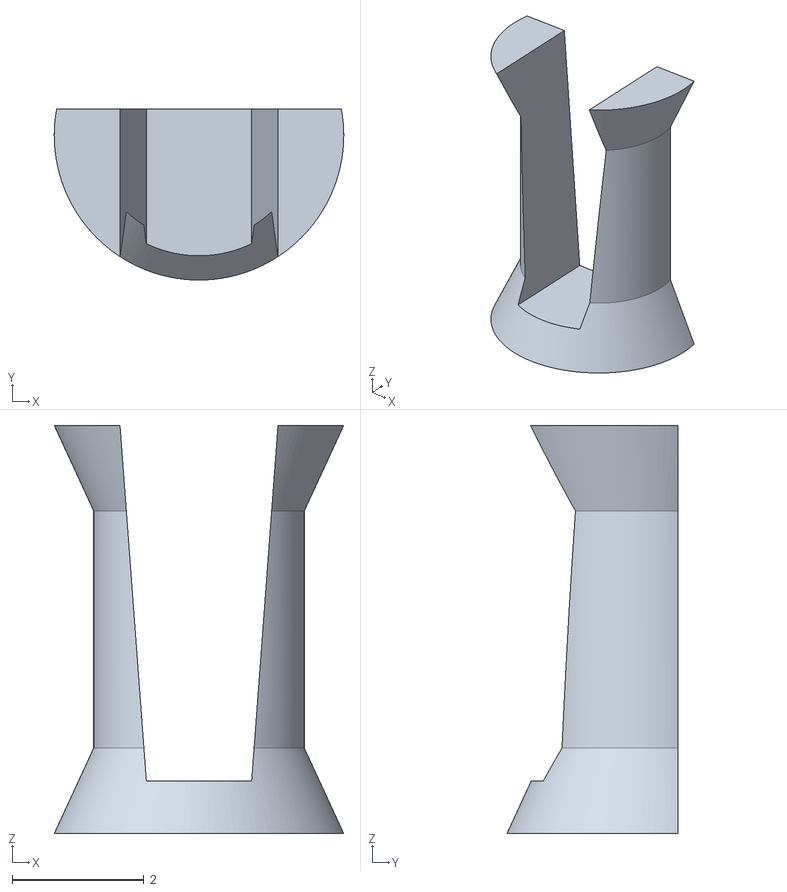
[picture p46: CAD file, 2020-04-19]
other/6.4/stl/clips/blocker-2.stl
4.40 x 2.60 x 6.20

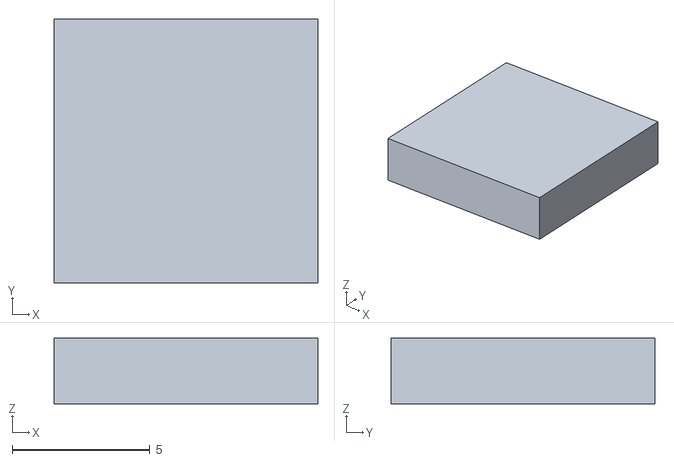
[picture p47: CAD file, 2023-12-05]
other/blender/test2.stl
9.60 x 9.60 x 2.40

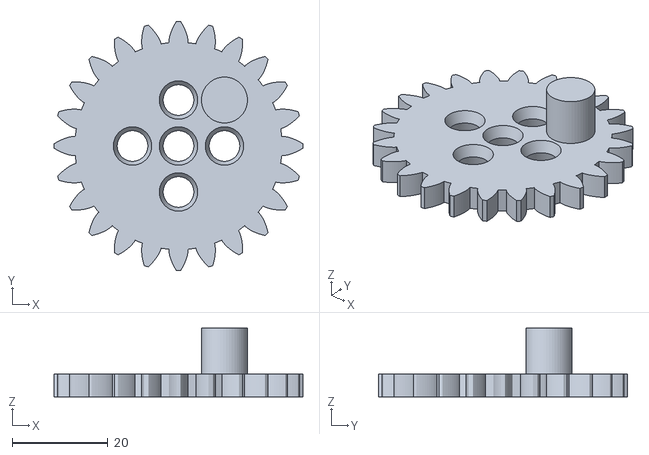
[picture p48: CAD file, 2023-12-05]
other/gears/stl/gears_helical-24-crank.stl
52.0 x 52.0 x 14.4

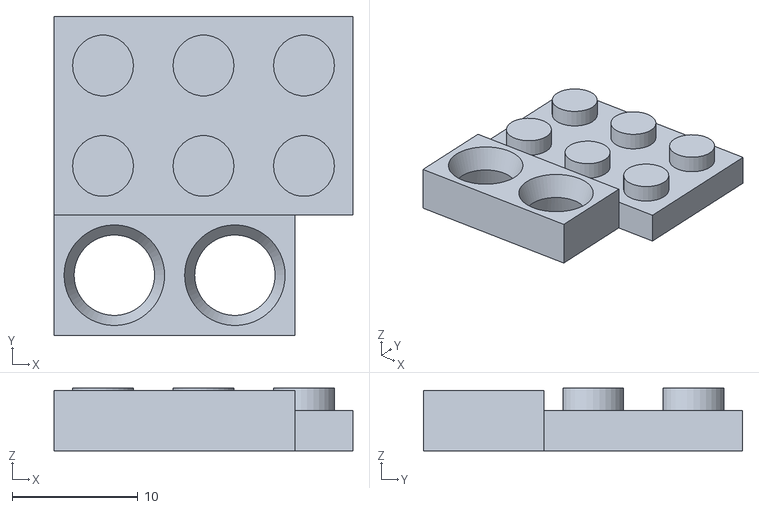
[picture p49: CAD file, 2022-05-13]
other/lego/stl/L4.stl
23.8 x 25.4 x 5.00

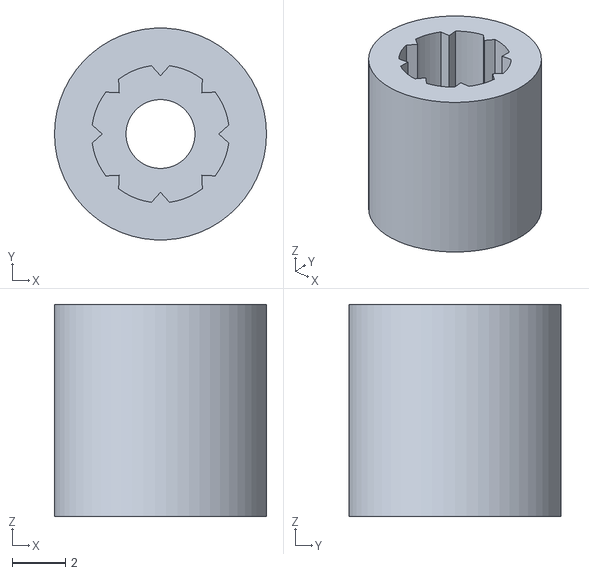
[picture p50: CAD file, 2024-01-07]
other/spiralwheel/imports/sg90-wheel.stl
8.00 x 7.99 x 8.00

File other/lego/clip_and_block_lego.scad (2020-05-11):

use <LEGO.scad>;

size =9.6;
model="LE";

// // 1x5-1x6
// width=1;
// length=6;
// height=1;
// holeArray=[[-1,0,0],[-1,1,0],[-1,2,0],[-1,3,0],[-1,4,0]];

// // 1x5-2x6
// width=2;
// length=6;
// height=1;
// holeArray=[[-1,0,0],[-1,1,0],[-1,2,0],[-1,3,0],[-1,4,0]];

// // 1x2-1x3
// width=1;
// length=3;
// height=1;
// holeArray=[[-1,0,0],[-1,1,0]];

// // 1x2-2x3
// width=2;
// length=3;
// height=1;
// holeArray=[[-1,0,0],[-1,1,0]];

// L1x2-L3x4
width=1;
length=3;
height=1/3;
holeArray=[[-1,0,0],[-1,1,0],[-2,0,0]];
width2=1;
length2=4;

// // 1x2-L3x3
width=1;
length=3;
height=1/3;
holeArray=[[-1,0,0],[-1,1,0]];
width2=1;
length2=3;



// // L1x2-L2x3
// width=1;
// length=2;
// height=1;
// holeArray=[[-1,0,0],[-1,1,0],[-2,0,0]];
// width2=1;
// length2=3;


finalRotate=[0,0,0];
finalMirror=[0,0,0];

rotate([finalRotate[0], finalRotate[1], finalRotate[2]]) {
mirror([finalMirror[0], finalMirror[1], finalMirror[2]]) {    
    // Model LE => Lego
    if (model == "LE") {
        block(
            type="brick",
            width=width,
            length=length,
            height=height
        );        
        
        if (width2 > 0) {
            translate([-7.8,7.8,0]) {
                rotate([0,0,270]) {
                    block(
                        type="brick",
                        width=width2,
                        length=length2,
                        height=height
                    );                   
                }            
            }

        }
            
        for(i= [0 : len(holeArray) - 1]) // rows
        {
            echo(str("row:",i));

            echo(str(holeArray[i][0], ",",holeArray[i][1], ",", holeArray[i][2] ));
            translate([holeArray[i][1]*size,holeArray[i][0]*size,holeArray[i][2]*size/2]) holeCube();

        }
        
    }

    // Model F => File
    if (model == "F") {
        import(str("imports/",filename));
        
        for(i= [0 : len(holeArray) - 1]) // rows
        {
            echo(str("row:",i));

            echo(str(holeArray[i][0], ",",holeArray[i][1], ",", holeArray[i][2] ));
            translate([holeArray[i][1]*size,holeArray[i][0]*size,holeArray[i][2]*size/2]) holeCube();

        }
    }

    // Model FH => File Half (Half height
    if (model == "FH") {
        import(str("imports/",filename));
        for(i= [0 : len(holeArray) - 1]) // rows
        {
            echo(str("row:",i));

            echo(str(holeArray[i][0], ",",holeArray[i][1], ",", holeArray[i][2] ));
            translate([holeArray[i][1]*size,holeArray[i][0]*size+size,holeArray[i][2]*size/2+size/4]) {
                rotate([180,0,0]) {
                    holeCubeHalf();
                }
            }
                

        }
    }

}//finalMirror
}//finalRotate

module holeCube() {
    import("../../imports/hole-cube.stl");
    /*difference() {
        cube([size,size,size/2]);
        translate([size/2, size/2, 0]) cylinder (h = size/4, r1=8/2, r2=6.4/2, center=false, $fn=100 );
       translate([size/2, size/2, size/4])  cylinder (h = 4.8, r1=6.4/2, r2=8/2, center=false, $fn=100 );
    }*/
}

module holeCubeHalf() {
   import("imports/hole-cube-half.stl");
    /*difference() {
        cube([size,size,size/2]);
        translate([size/2, size/2, 0]) cylinder (h = size/4, r1=8/2, r2=6.4/2, center=false, $fn=100 );
       translate([size/2, size/2, size/4])  cylinder (h = 4.8, r1=6.4/2, r2=8/2, center=false, $fn=100 );
    }*/
}   

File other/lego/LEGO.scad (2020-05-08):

/**
 * Derived from http://www.thingiverse.com/thing:5699
 *
 * LEGO®, the LEGO® logo, the Brick, DUPLO®, and MINDSTORMS® are trademarks of the LEGO® Group. ©2012 The LEGO® Group.
 */
 
 /**
  * For clip and block, i've :
  * remove Pin diameter (pin_diameter = 0)
  * spline_thickness (spline_thickness=0)
  */

/* [General] */

// Width of the block, in studs
block_width = 1;

// Length of the block, in studs
block_length = 6;

// Height of the block. A ratio of "1" is a standard LEGO brick height; a ratio of "1/3" is a standard LEGO plate height; "1/2" is a standard DUPLO plate.
block_height_ratio = 1; // [.33333333333:1/3, .5:1/2, 1:1, 2:2, 3:3, 4:4, 5:5, 6:6, 7:7, 8:8, 9:9, 10:10]

// What type of block should this be? For type-specific options, see the "Wings," "Slopes," "Curves", and "Baseplates" tabs.
block_type = "brick"; // [brick:Brick, tile:Tile, wing:Wing, slope:Slope, curve:Curve, baseplate:Baseplate]

// What brand of block should this be? LEGO for regular LEGO bricks, Duplo for the toddler-focused larger bricks.
block_brand = "lego"; // [lego:LEGO, duplo:DUPLO]

// What stud type do you want? Hollow studs allow rods to be pushed into the stud.
stud_type = "solid"; // [solid:Solid, hollow:Hollow]

// Should the block include round horizontal holes like the Technics LEGO bricks have?
technic_holes = "no"; // [no:No, yes:Yes]

// Should the block include vertical cross-shaped axle holes?
vertical_axle_holes = "no"; // [no:No, yes:Yes]

/* [Wings] */

// What type of wing? Full is suitable for the front of a plane, left/right are for the left/right of a plane.
wing_type = "full"; // [full:Full, left:Left, right:Right]

// The number of studs across the end of the wing. If block_width is odd, this needs to be odd, and the same for even.
wing_end_width = 2;

// The length of the rectangular portion of the wing, in studs.
wing_base_length = 3;

// Should the wing edges be notched to accept studs below?
wing_stud_notches = "yes"; // [yes:Yes, no:No]

/* [Slopes] */

// How many rows of studs should be left before the slope?
slope_stud_rows = 1;

// How much vertical height should be left at the end of the slope? e.g, a value of zero means the slope reaches the bottom of the block. A value of 1 means that for a block with height 2, the slope reaches halfway down the block.
slope_end_height = 0;

/* [Curves] */

// How many rows of studs should be left before the curve?
curve_stud_rows = 5;

// Should the curve be convex or concave?
curve_type = "concave"; // [concave:Concave, convex:Convex]

// How much vertical height should be left at the end of the curve? e.g, a value of zero means the curve reaches the bottom of the block. A value of 1 means that for a block with height 2, the curve reaches halfway down the block.
curve_end_height = 0;

/* [Baseplates] */

// If you want a roadway, how wide should it be (in studs)? A roadway is a smooth (non-studded) section of a baseplate.
roadway_width = 0;

// How long should the roadway be?
roadway_length = 0;

// Where should the roadway start (x-value)? A value of zero puts the roadway at the far left side of the plate.
roadway_x = 0;

// Where should the roadway start (y-value)? A value of zero puts the roadway at the front of the plate.
roadway_y = 0;

/* [SNOT] */

// SNOT means Studs Not On Top -- bricks with alternative stud configurations.
// Put studs on the top and buttom?
dual_sided = "no"; // [no:No, yes:Yes]

// Instead of both sides having studs, both sides can have no studs.
dual_bottom = "no"; // [no:No, yes:Yes]

/* [Printer-Specific] */

// Should extra reinforcement be included to make printing on an FDM printer easier? Ignored for tiles, since they're printed upside-down and don't need the reinforcement. Recommended for block heights less than 1 or for Duplo bricks. 
use_reinforcement = "no"; // [no:No, yes:Yes]

// If your printer prints the blocks correctly except for the stud diameter, use this variable to resize just the studs for your printer. A value of 1.05 will print the studs 105% wider than standard.
stud_rescale = 1;
//stud_rescale = 1.0475 * 1; // Orion Delta, T-Glase
//stud_rescale = 1.022 * 1; // Orion Delta, ABS

// Print tiles upside down.
translate([0, 0, (block_type == "tile" ? block_height_ratio * block_height : 0)]) rotate([0, (block_type == "tile" ? 180 : 0), 0]) {
    block(
        width=block_width,
        length=block_length,
        height=block_height_ratio,
        type=block_type,
        brand=block_brand,
        stud_type=stud_type,
        horizontal_holes=(technic_holes=="yes"),
        vertical_axle_holes=(vertical_axle_holes=="yes"),
        reinforcement=(use_reinforcement=="yes"),
        wing_type=wing_type,
        wing_end_width=wing_end_width,
        wing_base_length=wing_base_length,
        stud_notches=(wing_stud_notches=="yes"),
        slope_stud_rows=slope_stud_rows,
        slope_end_height=slope_end_height,
        curve_stud_rows=curve_stud_rows,
        curve_type=curve_type,
        curve_end_height=curve_end_height,
        roadway_width=roadway_width,
        roadway_length=roadway_length,
        roadway_x=roadway_x,
        roadway_y=roadway_y,
        stud_rescale=stud_rescale,
        dual_sided=(dual_sided=="yes"),
        dual_bottom=(dual_bottom=="yes")
    );
}

module block(
    width=1,
    length=2,
    height=1,
    type="brick",
    brand="lego",
    stud_type="solid",
    horizontal_holes=false,
    vertical_axle_holes=false,
    reinforcement=false,
    wing_type="full",
    wing_end_width=2,
    wing_base_length=2,
    stud_notches=false,
    slope_stud_rows=1,
    slope_end_height=0,
    curve_stud_rows=1,
    curve_type="concave",
    curve_end_height=0,
    roadway_width=0,
    roadway_length=0,
    roadway_x=0,
    roadway_y=0,
    stud_rescale=1,
    dual_sided=false,
    dual_bottom=false
    ) {
    post_wall_thickness = (brand == "lego" ? 0.85 : 1);
    wall_thickness=(brand == "lego" ? 1.3 : 1.5);
    stud_diameter=(brand == "lego" ? 4.85 : 9.35);
    hollow_stud_inner_diameter = (brand == "lego" ? 3.1 : 6.7);
    stud_height=(brand == "lego" ? 1.8 : 4.4);
    stud_spacing=(brand == "lego" ? 8 : 8 * 2);
    block_height=(brand == "lego" ? (type == "baseplate" ? 1.3 : 9.6) : 9.6 * 2);
    pin_diameter=(brand == "lego" ? 0 : 3 * 2);
    post_diameter=(brand == "lego" ? 5.5 : 13.2);
    cylinder_precision=(brand == "lego" ? 0.1 : 0.05);
    reinforcing_width = (brand == "lego" ? 0.7 : 1);

    spline_length = (brand == "lego" ? 0.25 : 1.7);
    spline_thickness = (brand == "lego" ? 0 : 1.3);

    horizontal_hole_diameter = (brand == "lego" ? 4.8 : 4.8 * 2);
    horizontal_hole_z_offset = (brand == "lego" ? 5.8 : 5.8 * 2);
    horizontal_hole_bevel_diameter = (brand == "lego" ? 6.2 : 6.2 * 2);
    horizontal_hole_bevel_depth = (brand == "lego" ? 0.9 : 0.9 * 1.5 / 1.2 );

    roof_thickness = (type == "baseplate" || dual_sided ? block_height * height : 1 * 1);

    // Brand-independent measurements.
    axle_spline_width = 2.0;
    axle_diameter = 5 * 1;
    wall_play = 0.1 * 1;
    horizontal_hole_wall_thickness = 1 * 1;

    // Ensure that width is always less than or equal to length.
    real_width = (type == "wing" ? width : min(width, length) );
    real_length = (type == "wing" ? length : max(width, length) );
    real_height = max((type == "baseplate" ? 1 : 1/3), height);

    // Ensure that the wing end width is even if the width is even, odd if odd, and a reasonable value.
    real_wing_end_width = (wing_type == "full"
        ?
        min(real_width - 2, ((real_width % 2 == 0) ? 
            (max(2, (
                wing_end_width % 2 == 0 ?
                (wing_end_width)
                :
                (wing_end_width-1)
            )))
            :
            (max(1, (
                wing_end_width % 2 == 0 ?
                (wing_end_width-1)
                :
                (wing_end_width)
            )))
        ))
        :
        (min(real_width-1, max(1, wing_end_width))) // Half-wing
    );

    // Ensure that the base length is a reasonable value.
    real_wing_base_length = min(real_length-1, max(1, wing_base_length)) + 1; // +1 because the angle starts before the last stud.
        
    // Validate all the rest of the arguments.
    real_slope_end_height = max(0, min(real_height - 1/3, slope_end_height));
    real_slope_stud_rows = min(real_length - 1, slope_stud_rows);
    real_curve_stud_rows = max(0, curve_stud_rows);
    real_curve_type = (curve_type == "convex" ? "convex" : "concave");
    real_curve_end_height = max(0, min(real_height - 1/3, curve_end_height));
    real_horizontal_holes = horizontal_holes && ((type == "baseplate" && real_height >= 8) || real_height >= 1) && !dual_sided;
    real_vertical_axle_holes = vertical_axle_holes && real_width > 1;
    real_reinforcement = reinforcement && type != "baseplate" && type != "tile" && !dual_sided;
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

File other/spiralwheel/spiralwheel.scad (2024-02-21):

/*   	Parametric airlehttps://news.google.com/?tab=wn&hl=fr&gl=FR&ceid=FR:frhttps://news.google.com/?tab=wn&hl=fr&gl=FR&ceid=FR:frss tire
		by Travis Howse <tjhowse@gmail.com>
		2012.   License, GPL v2 or later
**************************************************/
// https://www.thingiverse.com/thing:17514/files
type="sg90"; // clip, washer, dc-gearbox, sg90

dia_out = 45;//65;
height = 10;
spoke_count = 5;
spoke_thickness = 1;
tread_thickness = 1;

 r1=3.2; 
 r2=2.75;

dia_in = 1;
hub_thickness = 7;

$fn = 30;
spoke_dia = (dia_in/2) + hub_thickness + (dia_out/2) - tread_thickness+spoke_thickness;
grip_density = 0.05;//0.05; // Set to 0 for no grip.
grip_height = 1.;
grip_depth = 2;
pi = 3.14159;
zff = 0.001;
washer_height = height;

//Set to 1 for a double spiral.
// Note: single-wall spokes probably won't work with double spirals, as the
// first layer of the upper spiral would bridge in a straight line, rather
// than a curve. Successive layers probably wouldn't recover.
double_spiral = 0;

module wheel()
{
	difference()
	{
		cylinder(r=dia_out/2,h=height);
		cylinder(r=(dia_out/2)-tread_thickness,h=height);	
	}

	difference()
	{
		cylinder(r=(dia_in/2)+hub_thickness,h=height);
		cylinder(r=dia_in/2,h=height);	
	}

	for (i = [0:spoke_count-1])
	{
		if (double_spiral)
		{
			rotate([0,0,i * (360/spoke_count)]) translate([(spoke_dia/2)-(dia_in/2)-hub_thickness,0,(height/2)+zff]) spoke();
			rotate([180,0,i * (360/spoke_count)]) translate([(spoke_dia/2)-(dia_in/2)-hub_thickness,0,-height/2]) spoke();			
		} else {
			rotate([0,0,i * (360/spoke_count)]) translate([(spoke_dia/2)-(dia_in/2)-hub_thickness,0,0]) spoke();
		}
	}
	
	if (grip_density != 0)
	{
		for (i = [0:(360*grip_density)])
		{
			rotate([0,0,i*(360/(360*grip_density))]) translate([dia_out/2-grip_height/2,0,0]) cube([grip_height,grip_depth,height]);
		}
	}
}

module spoke()
{
	intersection()
	{
		difference()
		{
			cylinder(r=spoke_dia/2,h=height);
			cylinder(r=(spoke_dia/2)-spoke_thickness,h=height);	
		}
		if (double_spiral)
		{
			translate([-spoke_dia/2,-spoke_dia,0]) cube([spoke_dia,spoke_dia,height/2]);
		} else {
			translate([-spoke_dia/2,-spoke_dia,0]) cube([spoke_dia,spoke_dia,height]);
		}
	}
}

if (type == "clip") {
    mirror([0,0,1]) {
        translate([0,0,-height]) {
            difference() {
                wheel();
                
                // Center of the wheel
                cylinder(h=height, r1=3.6, r2=3.6, center=false);
                cylinder(h=height - 3.2, r=5.15, center=false);
            }
        }
    }
    
}

//Washer
if (type == "washer") {
    difference() {
        // Center of the wheel
        cylinder(h=height, r1=hub_thickness, r2=hub_thickness, center=false);
        cylinder(h=height, r=3.6, center=false);
    }
}

if (type == "dc-gearbox") {
    
    mirror([0,0,1]) {
        translate([0,0,-height]) {
            
            difference() {
                union() {
                    translate([0,0,-washer_height]) {
                        cylinder(h=height + washer_height, r=hub_thickness);
                    }
                    wheel();
                }
                
                //cylinder(h=10, r=4 , center=false);
                translate([0,0,-washer_height]) {
                    cylinder(h=7+washer_height, r1=r1, r2=r2 , center=false);
                }
                

            }

            translate([1.9,-3,0-washer_height])
                cube([2,6,height+washer_height]);

            translate([-1.9-2,-3,0-washer_height])
                cube([2,6,height+washer_height]);
            
        }
    }
}

if (type == "sg90") {
    
    mirror([0,0,1]) {
        union() {
            difference() {
                wheel();
                cylinder(h=7+washer_height, r1=r1, r2=r2 , center=false);
            }
            
            translate([0,0,height-8]) { // 8mm is the height of sg90-wheel.stl
                import("imports/sg90-wheel.stl");   
            }
        }
    }
}

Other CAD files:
other/spiralwheel/stl/SP65-medium-clip.stl
stl/basic-parts/P-5-4.stl
stl/clips/clip-6-M4.stl
stl/electronic-parts/arduino-nano/nano-bottom-2side.stl
other/wheel/wheel.scad
clip_and_block.scad
clip_and_block_generic.scad
clip_and_block_nice.scad
dat/clips/clip-3a.stl
dat/clips/clip-4a.stl
dat/other/other-L9110.stl
dat/other/other-dc-motor-gearbox.stl
dat/other/other-sg90.stl
imports/18650x2-holder.stl
imports/AntifognoseclipV.2.stl
imports/D1-mini-generic.stl
imports/D1-mini.stl
imports/TM1637-bottom.stl
imports/TM1637-top.stl
imports/battery-shield-bottom.stl
imports/battery-shield-usb.stl
imports/bme280.stl
imports/breadboard25.stl
imports/button14x20-bottom.stl
imports/button14x20-bottomx2.stl
imports/button14x20-half-bottom.stl
imports/button14x20-half-bottomx2.stl
imports/button14x20-half-top.stl
imports/button14x20-half-topx2.stl
imports/button14x20-top.stl
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

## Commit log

2019-08-03 Add l9110s
    [I-1.stl, I-10.stl, I-11.stl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]
2019-08-04 conic clip and blocker
    [blocker-2.stl, clip-2.stl]
2019-08-06 New l9110s, New blocker, new IS
    [IS-2.stl, IS-3.stl, IS-4.stl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]
2020-03-27 New clips and blockers - easier to print
    [blocker-2.stl, blocker-3.stl, blocker-4.stl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]
2020-03-28 Nouvelles plaques + doc
    [C-2-1-1.stl, C-2-2-1.stl, C-2-2-2.stl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]
2020-04-19 test 6.4mm
    [I-4.stl, P-2-2.stl, blocker-2.stl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]
2020-04-22 New licence
    [involute_gears.scad, test1.stl]
2020-05-04 New U plate
    [C-2-1-1.stl, C-2-2-1.stl, C-2-2-2.stl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]
2020-05-04 New SG90
    [list-elec.csv, sg90-2x1-1side.stl, sg90-2x1-front.stl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]
2020-05-05 Generate preview with new generate-all script
    [clip_and_block.scad, list-all.csv]
2020-05-05 Add spiralWheel
    [clip-2.stl, clip-2a.stl, clip-3.stl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]
2020-05-06 new clip
    [blocker-2.stl, clip-2.stl, list-all.csv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]
2020-05-07 English readme and new blockers
    [blocker-2.stl, blocker-3.stl, blocker-4.stl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]
2020-05-07 new size spiralwheel
    [spiralwheel-rear.scad, spiralwheel-rear.stl]
2020-05-10 srong wire
    [blocker-2.stl, list-all.csv, wire-3H-strong.stl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]
2020-05-11 New order and generate scripts
    [18650x2-holder-1.stl, 18650x2-holder-bottom.stl, 18650x2-holder.stl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]
2020-05-13 new generate parts
    [L1.stl, L2.stl, L3.stl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]
2020-05-14 Change directory name
    [dupontx2.stl, dupontx4.stl, dupontx6.stl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]
2020-05-17 new blockers
    [SP65-clip.stl, blocker-2-strong.stl, blocker-2.stl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]
2020-05-18 add easy/strong clips
    [blocker-2-easy.stl, blocker-2-strong.stl, blocker-2.stl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]
2020-05-18 add P-5-2
    [P-5-2.stl, basic-parts.csv, blocker-5.stl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]
2020-05-19 add directory to electonic parts
    [electronic-parts.csv, nodemcu-top-small.stl, nodemcu-top.stl]
2020-05-19 new node mcu and electronic parts directory
    [18650x2-holder-1.stl, 18650x2-holder-bottom.stl, 18650x2-holder.stl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]
2020-05-21 Add clip-6
    [blocker-5.stl, blocker-6.stl, clip-6.stl]
2020-05-21 remove blocker-6 (does not work)
    [blocker-6.stl, clip-6.stl]
2020-06-02 test 12.8
    [C-2-1-1.stl, C-3-1-1.stl, C-4-1-1.stl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]
2021-04-26 Add n20 motors
    [AntifognoseclipV.2.stl, I-1.stl, L1.stl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]
2021-04-27 Generic corner
    [I-1.stl, electronic-parts.csv, generic-corner-1-0-0.stl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]
2021-04-29 New generic scad
    [clip_and_block.scad, clip_and_block_generic.scad, electronic-parts.csv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]
2021-04-29 New generic corner
    [clip_and_block_generic.scad, corner-1-1-0.stl, corner-1-1-1.stl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]
2021-10-21 First try for leocad
    [assembly.blend, clip_and_block_generic.scad, clipnblock.blend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]
2022-05-13 Add M4 + generic corners
    [C-2-1-1.stl, C-2-2-1.stl, C-2-2-2.stl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]
2023-08-20 big commit
    [18650x2-holder-1.stl, 18650x2-holder-bottom.stl, 18650x2-holder.stl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]
2023-08-28 Add computed generic
    [battery-shield-usb-2.3mf, clip-5-M4.stl, clip-6-M4.stl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]
2023-08-30 New clip_and_block_generic.scad
    [D1-mini-generic.stl, D1-mini.stl, battery-shield-bottom-2.stl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]
2023-09-15 Add SG90-helix
    [D1-mini-small.stl, breadboard25-2.stl, breadboard25-3.stl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]
2023-11-19 Add gears
    [gears_helical-14.stl, gears_helical-19.stl, gears_helical-23-14.stl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]
2023-12-05 Add pn532 and tm1638
    [Main V3 - clip-2-M4.stl, assembly.blend, clip_and_block_generic.scad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]
2024-01-07 Clip M4
    [SP45-hard-clip.stl, SP45-hard-dc-gearbox.stl, SP45-hard-sg90.stl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]
2024-01-11 multiple things :)
    [C-2-1-1.stl, C-2-2-1.stl, C-2-2-2.stl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]
2024-01-11 Add nodemcu-generic
    [clip_and_block_generic.scad, nodemcu-generic.stl]
2024-01-14 add joystick
    [18650x2-holder-1.stl, 18650x2-holder-bottom.stl, 18650x2-holder.stl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]
2024-02-18 Adjust SG90 wheels
    [SP45-hard-clip.stl, SP45-hard-dc-gearbox.stl, SP45-hard-sg90.stl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]
2024-02-21 Add P-5-4.stl
    [P-5-4.stl, basic-parts.csv, center-sg90.stl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]
2024-02-28 remove generic add switch
    [corner-1-1-0.stl, corner-1-1-1.stl, corner-1-1-2.stl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]
2024-02-28 remove rc-car
    [IR-1.stl]
2024-02-28 Add direction-center
    [direction-center.stl]
